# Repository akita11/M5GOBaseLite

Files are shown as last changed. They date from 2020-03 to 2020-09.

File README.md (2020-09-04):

# M5GOBaseLite

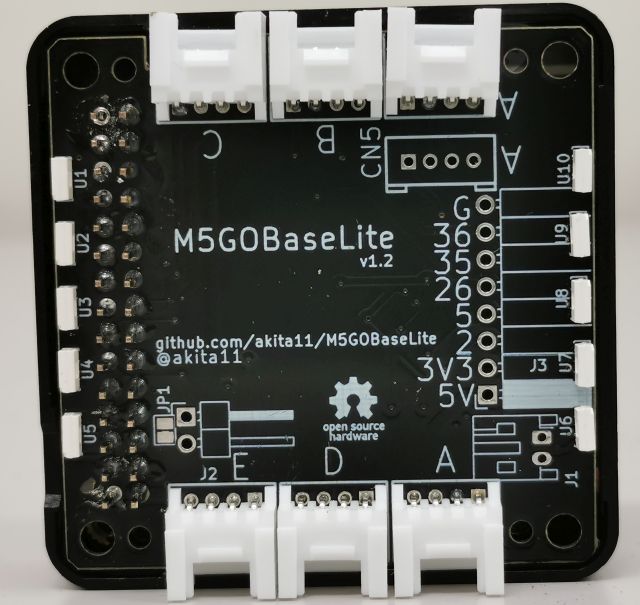
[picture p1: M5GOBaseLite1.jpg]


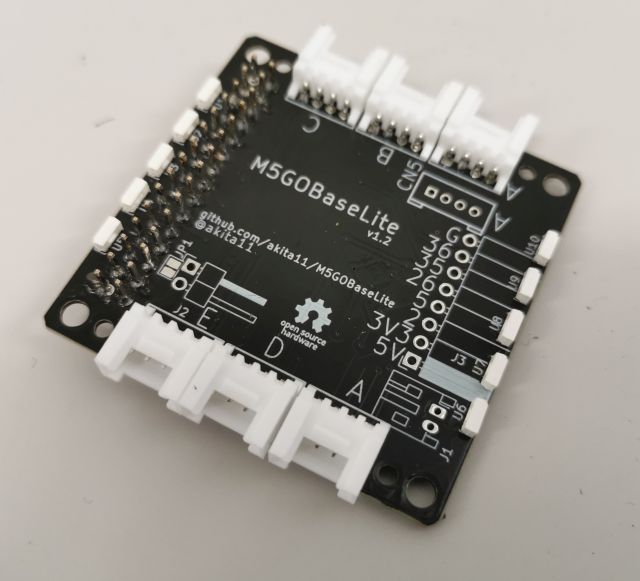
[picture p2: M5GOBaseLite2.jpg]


M5Stackの上部本体(Core/Core2)にとりつけて、以下のようなM5GO/Fireの機能やそれ以外の機能を追加できる底板（ベースボード）用の拡張基板です。
- Groveコネクタ(PortA(2個), PortB, PortC, PortD, PortE)（PortA/B/CはM5Stack純正のものと同等です。PortD/EはM5Stack純正品にはありませんが、UI Flowで使用することができるポートです）
- 左右5個ずつのNeoPixel (SK6812)
- LiPoバッテリ接続端子

# 使い方
1. M5Stackの本体(Core、底板を外した状態)に本ボードを差し込みます。
2. M5Stackのプログラムから、Groveコネクタに接続したセンサ類や左右のNeoPixelを使用します。
   - 左右のNeoPixelの制御信号はGPIO15につながっています。UI Flowでは、Hardware→RGB LED、から使用できます
   - 各Groveコネクタのピン配置は以下の通り（中央寄りのVDDから近い側、遠い側の順）
     - PortA: GPIO21(SDA), GPIO22(SCL)
     - PortB: GPIO26, GPIO36
     - PortC: GPIO17(TXD2), GPIO16(RXD2) (Core2ではGPIO14(TXD2), GPIO13(RXD2))
     - PortD: GPIO35, GPIO34
     - PortE: GPIO13, GPIO5 (Core2ではGPIO19, GPIO33)

※2020/9/4現在、Core2のUIFlowではPortB, C, D, Eは選択できませんので、ポート割当でCustomを選択し、上記のIOピンを指定してください。

# 底面カバー

M5GOBaseLite_cover.svgを厚さ5mmのアクリル板等でカットすると、底面カバーにできます。

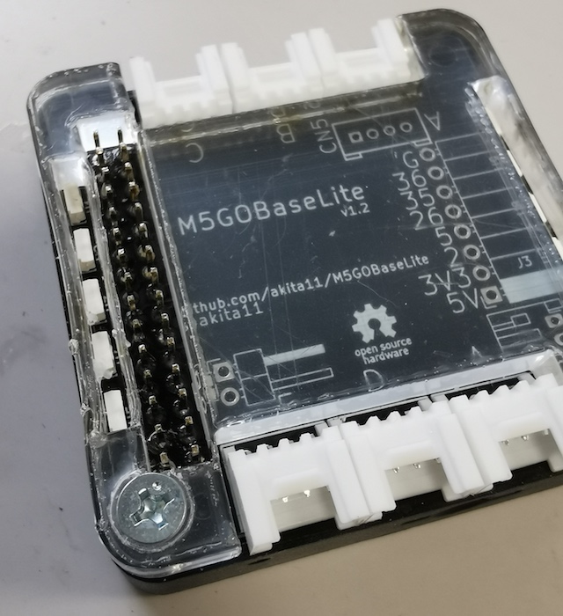
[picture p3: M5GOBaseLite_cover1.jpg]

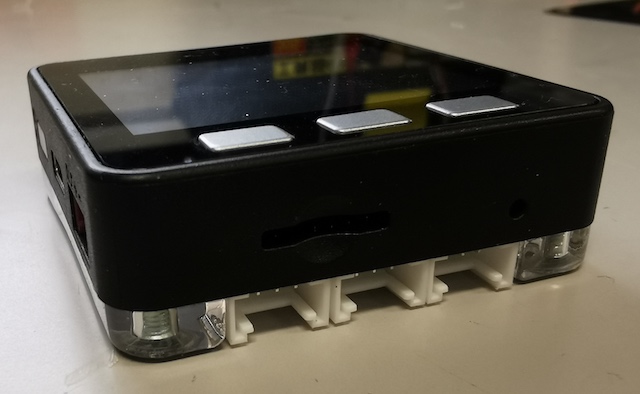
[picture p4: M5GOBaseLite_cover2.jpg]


# Author

Junichi Akita (@akita11, akita@ifdl.jp)

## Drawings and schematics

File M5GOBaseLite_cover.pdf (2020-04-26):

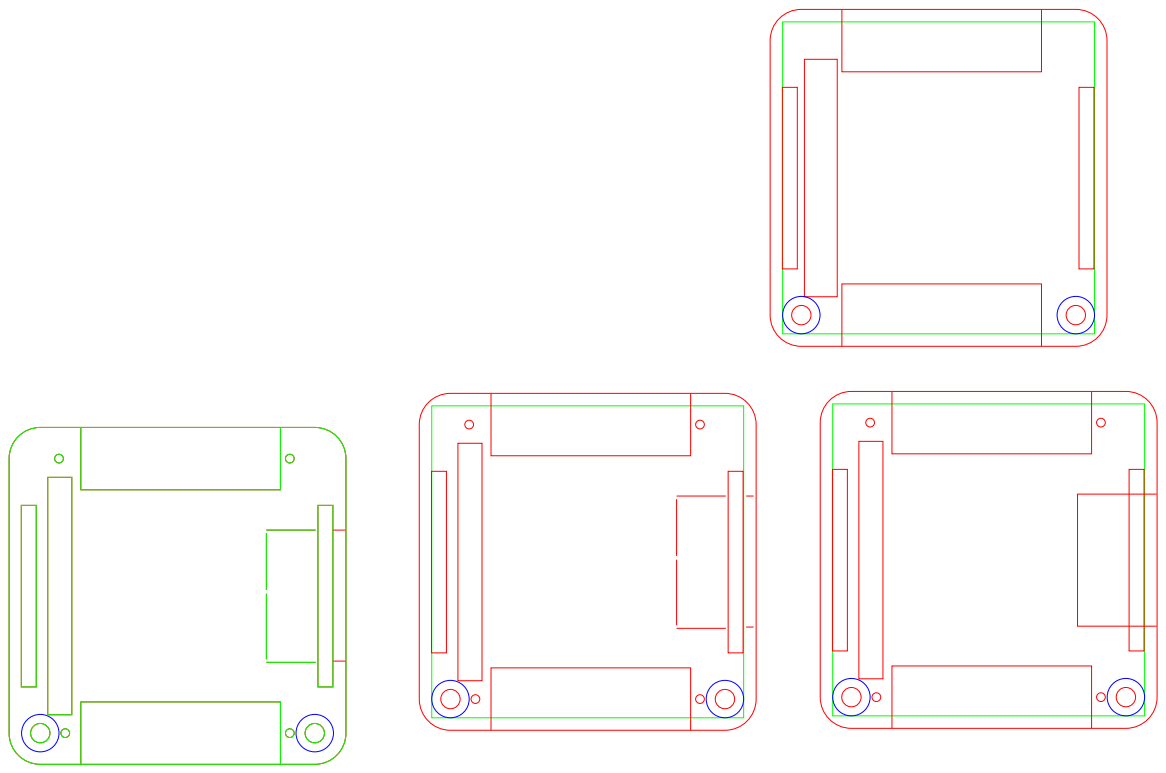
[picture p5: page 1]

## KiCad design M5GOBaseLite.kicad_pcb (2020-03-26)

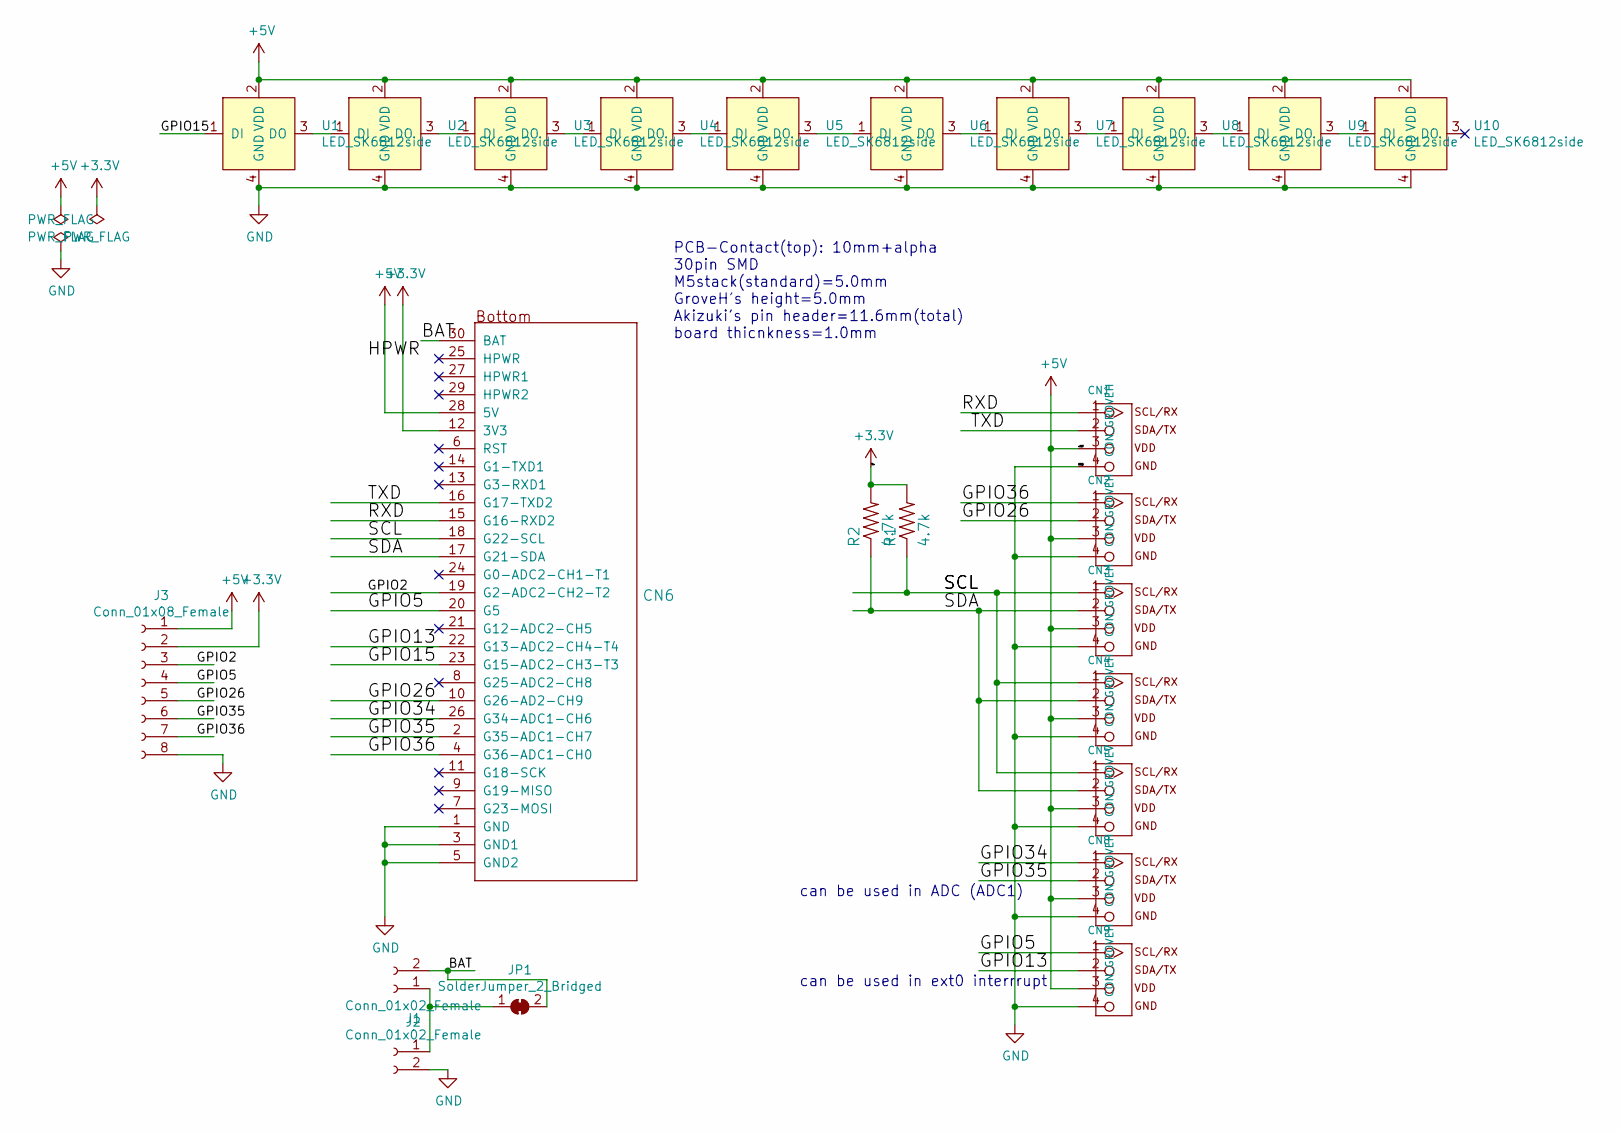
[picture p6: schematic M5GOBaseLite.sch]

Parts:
CN1, CN2, CN3, CN4, CN8, CN9: CON_GROVEH; CON_GROVE_H
CN5: CON_GROVEV; CON_GROVE_V
CN6: MBUS_bottom; PinSocket_2x15_P2.54mm_Vertical_SMD
J1: Conn_01x02_Female; JST_PH_S2B-PH-K_1x02_P2.00mm_Horizontal
J2: Conn_01x02_Female; PinHeader_1x02_P2.54mm_Horizontal
J3: Conn_01x08_Female; PinSocket_1x08_P2.54mm_Horizontal
JP1: SolderJumper_2_Bridged; SolderJumper-2_P1.3mm_Bridged_Pad1.0x1.5mm
R1, R2: 4.7k; 0603
U1, U2, U3, U4, U5, U6, U7, U8, U9, U10: LED_SK6812side; LED_SK6812SIDE

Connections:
+3V3: CN6.12 (3V3), J3.2, R1.2, R2.2
+5V: CN1.3, CN2.3, CN3.3, CN4.3, CN5.3, CN6.28 (5V), CN8.3, CN9.3, J3.1, U1.2 (VDD), U2.2 (VDD), U3.2 (VDD), U4.2 (VDD), U5.2 (VDD), U6.2 (VDD), U7.2 (VDD), U8.2 (VDD), U9.2 (VDD), U10.2 (VDD)
/BAT: CN6.30 (BAT), J2.2, JP1.2 (B)
/GPIO2: CN6.19 (G2-ADC2-CH2-T2), J3.3
/GPIO5: CN6.20 (G5), CN9.1, J3.4
/GPIO13: CN6.22 (G13-ADC2-CH4-T4), CN9.2
/GPIO15: CN6.23 (G15-ADC2-CH3-T3), U1.1 (DI)
/GPIO26: CN2.2, CN6.10 (G26-AD2-CH9), J3.5
/GPIO34: CN6.26 (G34-ADC1-CH6), CN8.1
/GPIO35: CN6.2 (G35-ADC1-CH7), CN8.2, J3.6
/GPIO36: CN2.1, CN6.4 (G36-ADC1-CH0), J3.7
/RXD: CN1.1, CN6.15 (G16-RXD2)
/SCL: CN3.1, CN4.1, CN5.1, CN6.18 (G22-SCL), R1.1
/SDA: CN3.2, CN4.2, CN5.2, CN6.17 (G21-SDA), R2.1
/TXD: CN1.2, CN6.16 (G17-TXD2)
GND: CN1.4, CN2.4, CN3.4, CN4.4, CN5.4, CN6.1 (GND), CN6.3 (GND1), CN6.5 (GND2), CN8.4, CN9.4, J1.2, J3.8, U1.4 (GND), U2.4 (GND), U3.4 (GND), U4.4 (GND), U5.4 (GND), U6.4 (GND), U7.4 (GND), U8.4 (GND), U9.4 (GND), U10.4 (GND)
unnamed: J1.1, J2.1, JP1.1 (A)
unnamed: U1.3 (DO), U2.1 (DI)
unnamed: U2.3 (DO), U3.1 (DI)
unnamed: U3.3 (DO), U4.1 (DI)
unnamed: U4.3 (DO), U5.1 (DI)
unnamed: U5.3 (DO), U6.1 (DI)
unnamed: U6.3 (DO), U7.1 (DI)
unnamed: U7.3 (DO), U8.1 (DI)
unnamed: U8.3 (DO), U9.1 (DI)
unnamed: U9.3 (DO), U10.1 (DI)

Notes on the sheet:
can be used in ext0 interrrupt
can be used in ADC (ADC1)
PCB-Contact(top): 10mm+alpha 30pin SMD M5stack(standard)=5.0mm GroveH's height=5.0mm Akizuki's pin header=11.6mm(total) board thicnkness=1.0mm

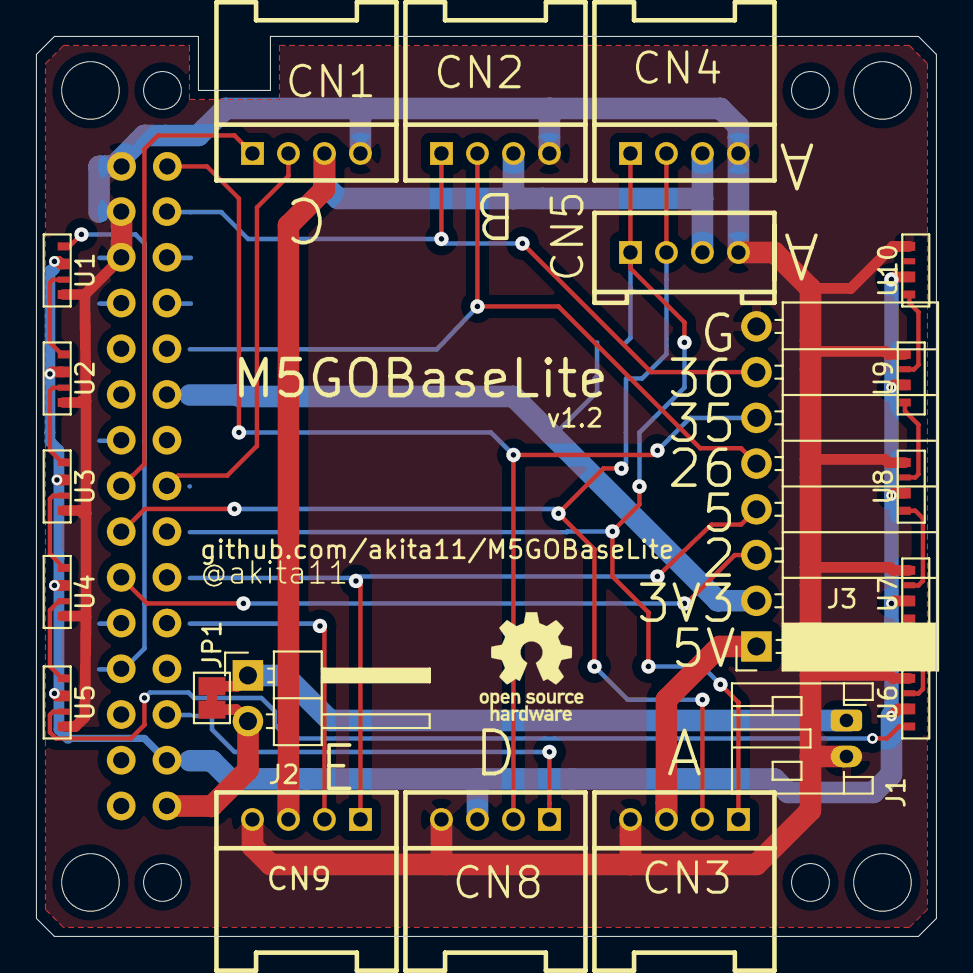
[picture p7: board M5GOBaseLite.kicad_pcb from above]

Board: 2 copper layers, 50.0 x 50.0 mm, 32 parts (0 on the bottom side), 26 nets.

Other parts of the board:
MH1, MH1#2, MH1#3, MH2: MountingHole_3.2mm_M3
MH5, MH5#2, MH5#3, MH5#4: MountingHole_2.1mm

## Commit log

2020-03-26 ファイル一式の追加、READMEの追記
    [M5GOBaseLite.kicad_pcb, M5GOBaseLite.sch]
2020-03-27 カバーのデータを追加
2020-03-27 カバーつきの写真を追加
2020-03-27 写真のファイル名を修正
2020-04-08 カバーのデータの追加
2020-04-22 カバーの細い側が切れやすいのでマージンを太めに
2020-04-26 カバーのカット部を微調整
2020-09-04 Core2の情報を記載
